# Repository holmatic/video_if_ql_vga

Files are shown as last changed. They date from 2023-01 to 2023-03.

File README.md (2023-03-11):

# **QLpicoVGA** - Video Interface QL-to-VGA with a Pi Pico 

This project creates the firmware for a DIY video interface based on the Rapsberry Pi Pico controller. It allows to connect a Sinclair QL computer to a standard VGA monitor.

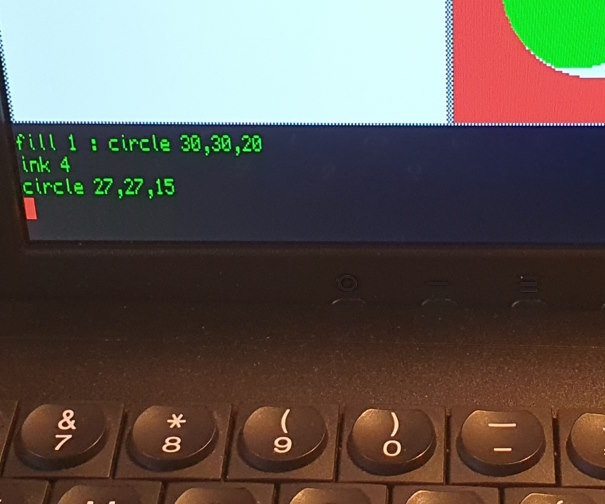
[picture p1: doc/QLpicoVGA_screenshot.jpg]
Screen VGA Monitor Connected to the QL


One difficulty when using an old Sinclair QL nowadays is finding monitor that works well. The QL video output is a bit non-standard, many displays do not show the full 512 horizontal pixel, but instead crop the screen in some way.

This small Video-to VGA converter project is specially made for the QL signal and translates the 512x256 pixel screen to a standard pseudo-XGA resolution (1024x768 with a single QL pixel translating to a block of 2x3 XGA pixels). The Gold Standard for such a translation is the "QL-VGA" FPGA-based device by MarcelK. This project is a µC based C/C++ implementation, utilizing the highly configurable I/O of the RP2040 and its DMA capabilities for signal input and output. Phase and frequency detection and adjustment is done by the CPU on the fly utilizing fixed-point arithmetics.

- The VGA signal generation uses _MoeFH_'s simple but clever DMA-driven approach for the low-level part. Kudos to _MoeFH_!
- QL video signals are sampled at 32MS/s - with the QL Pixel clock running at 10MHz
- All timing parameters are specifically preset for the QL's video output, so the software will definitely not work well with any other video source, the project is not meant as a generic RGB-to-VGA converter.
- As a small diagnostic aid, the unavoidable "No Signal" bluescreen shows a simplified logic-analyzer type of graph for the input signals

## Hardware

This project is based on a Raspberry Pi Pico board and only needs a few additional components (resistors) for voltage level translation:

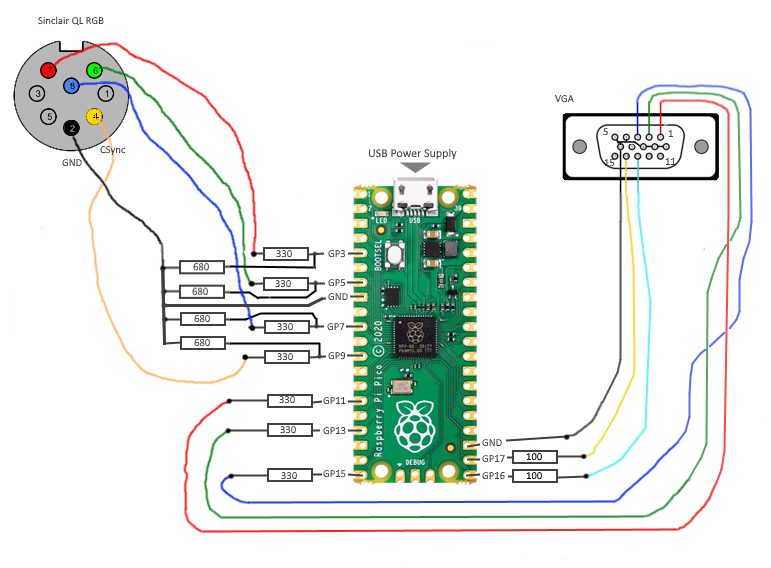
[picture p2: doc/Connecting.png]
Schematic outline How to connect QL, Pi Pico, and the VGA Monitor


```
Controller Module: Raspberry Pi Pico 
```

## QL to Pico:

```
QL RGB                            Pi Pico
Connector                          Module

7 (QLRED)   ----[R 330 Ohm]----  GP3=Pin 5 ----[R 680 Ohm]---- GND 
6 (QLGREEN) ----[R 330 Ohm]----  GP5=Pin 7 ----[R 680 Ohm]---- GND
8 (QLBLUE)  ----[R 330 Ohm]----  GP7=Pin10 ----[R 680 Ohm]---- GND

4 (QLCSYNC) ----[R 100 Ohm]----  GP9=Pin12 ----[R 680 Ohm]---- GND

2 (QLGND)   -------------------  GND=Pin8

```

## Pico to VGA:

```
Pi Pico                          VGA
Module                        Connector

GP11=Pin15 ----[R 330 Ohm]----  1 (RED)
GP13=Pin17 ----[R 330 Ohm]----  2 (GREEN)
GP15=Pin20 ----[R 330 Ohm]----  3 (BLUE)

GP16=Pin21 ----[R 100 Ohm]---- 13 (HSYNC)
GP17=Pin22 ----[R 100 Ohm]---- 14 (VSYNC)

GND=Pin23  ------------------- 6,7,8,10,5 (GND)
```

Note: Place all resistors close to the Pi Pico module (<5cm) for best signal integrity.

## Power Supply Input

Raspberry Pi Pico needs a standard USB power suppy (needs <100mA, so no special requirements for the power supply). Some VGA monitors may even provide USB voltage via an integrated USB hub. 

## 1st Prototype

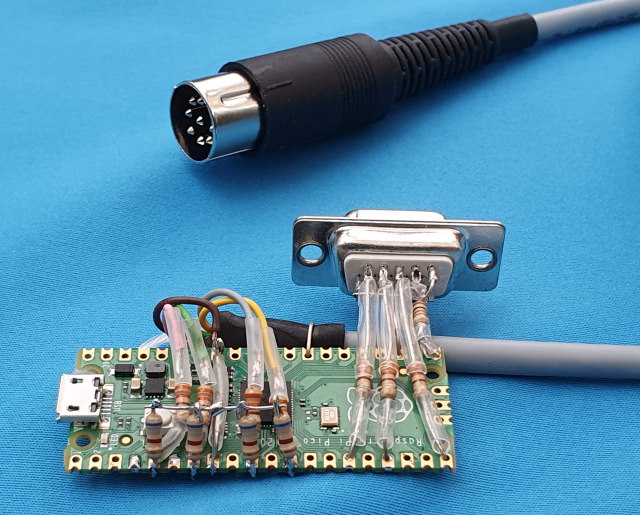
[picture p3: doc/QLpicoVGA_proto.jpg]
Prototype Quick-n-dirty prototype


(Ehem - yes I know but it works ;-)	

# Loading the Firmware into the Pi Pico

Pi Pico operates like a USB memory stick when pushing the BOOTSEL button during while plugging into the USB port of a computer. Put the firmware "video_if_ql_vga.uf2" onto the drive. LED should show short flashes with a period of about 2 seconds. Please also refer to the Pi Pico documentation regarding firmware programming.

https://github.com/holmatic/video_if_ql_vga/releases

## PCB and 3D Printable Case

So [here](doc/pcb.md) for info on creating your own PCB and case

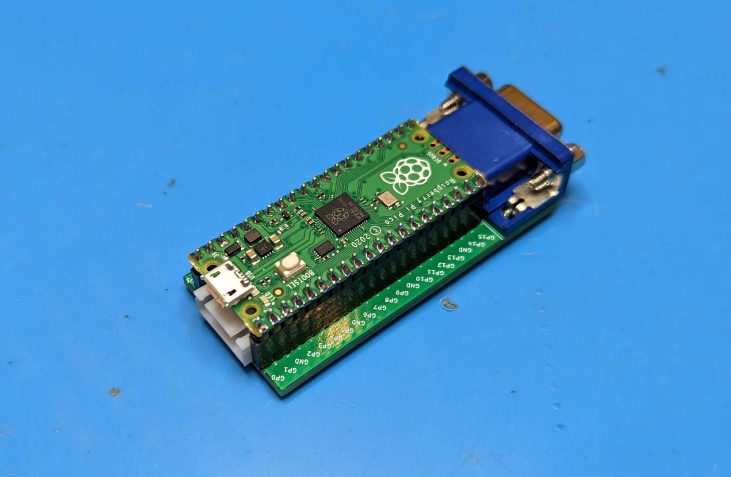
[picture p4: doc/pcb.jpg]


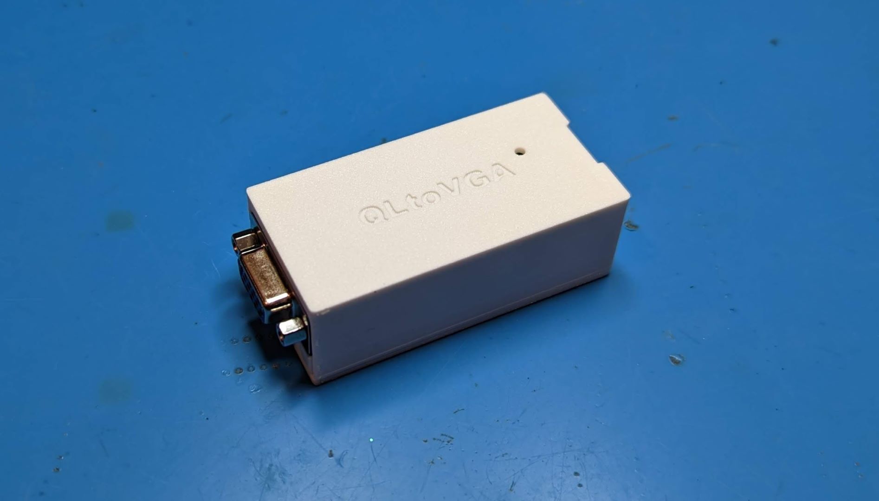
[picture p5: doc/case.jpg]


### Version Info

0.01 Initial version

0.05 Extend boot delay (startup fix for issue opbserved on some boards); minor adjustments to timing

---

Instruction v1.0

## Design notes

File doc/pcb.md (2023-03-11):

## PCB

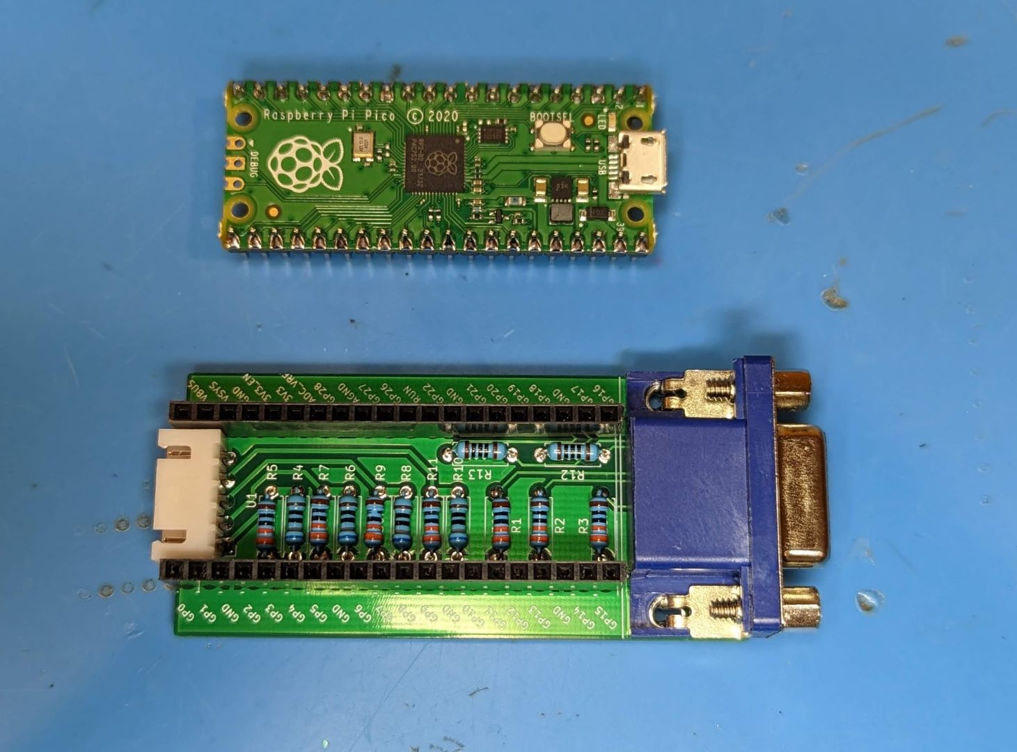
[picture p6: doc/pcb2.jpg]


To create your own PCB, send the gerber files off to your favorite PCB fab. There is an interactive BOM at [ibom.html](ibom.html), but most values are marked on the board itself.  All components can be sourced from the usual low cost Chinese vendors (AliExpress, etc.).

This is the VGA connector I used, https://www.aliexpress.us/item/2255799889288258.html

The Pico is mounted on 8.5mm tall 2.54mm female headers with 2.54mm male headers.

https://www.aliexpress.us/item/3256803886961825.html

For the video input, you can use any standard right angle 2.54mm spaced header or even solder the wires to the board. I went with an 5p XH2.54 connector which clips together a bit more securingly

https://www.aliexpress.us/item/2251832577362029.html

and then you can use the precrimped cables to make your input cable with a standard DIN 9 connector.  I sleeved the cable to make it look a little nicer, but that's optional.

https://www.aliexpress.us/item/2251832810520679.html

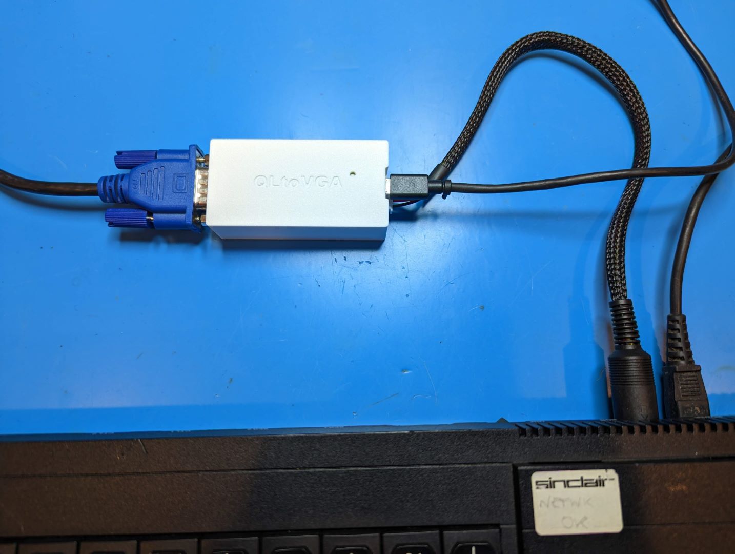
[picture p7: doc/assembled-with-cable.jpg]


## Case

The case is a simple snapfit design done in DesignSpark.  It's optimized to be printed at 0.2mm layer height with no need for supports.

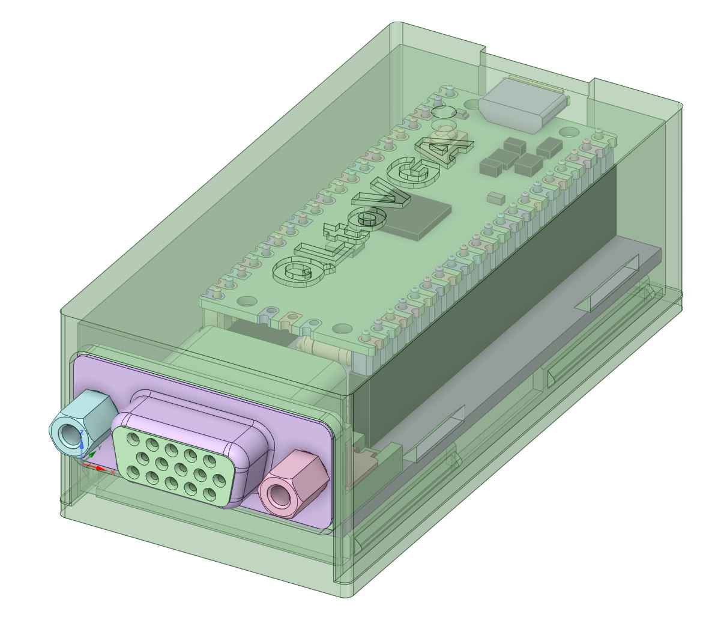
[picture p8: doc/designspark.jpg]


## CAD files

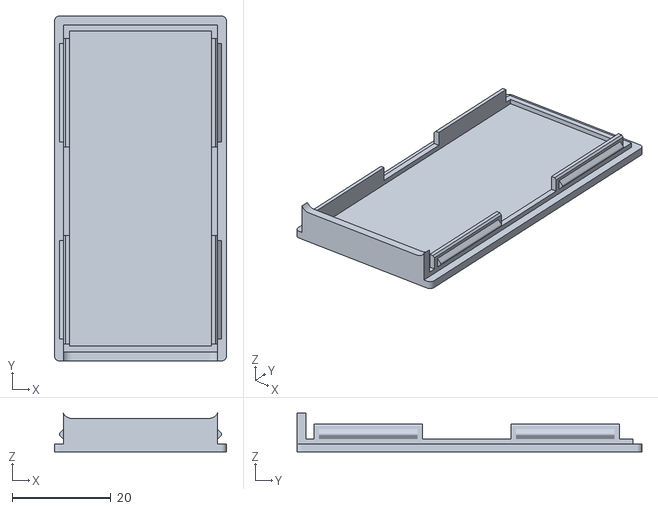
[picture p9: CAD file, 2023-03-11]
case/video_if_ql_vga-lid.stl
34.9 x 70.0 x 7.83

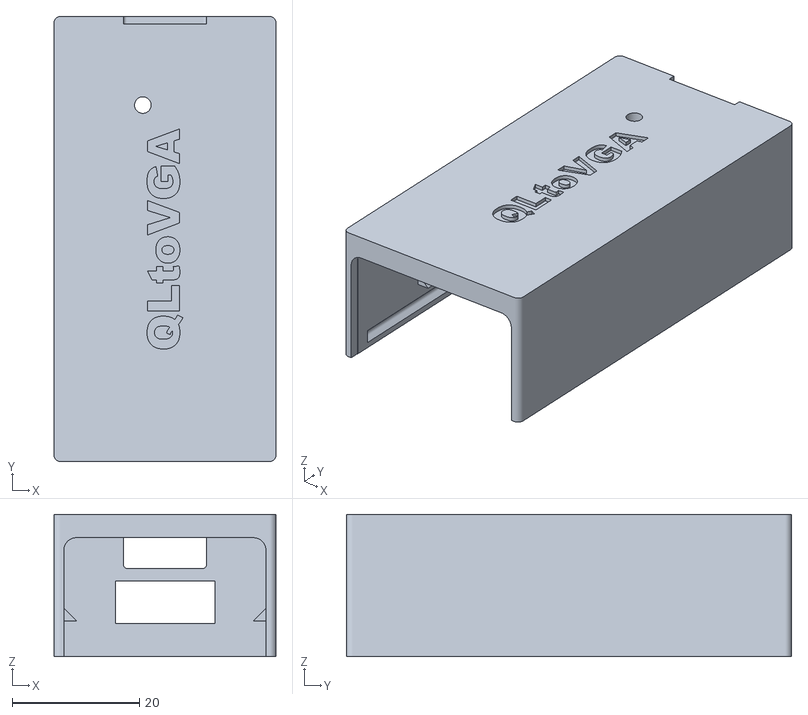
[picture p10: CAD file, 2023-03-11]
case/video_if_ql_vga-body.stl
34.9 x 70.0 x 22.4

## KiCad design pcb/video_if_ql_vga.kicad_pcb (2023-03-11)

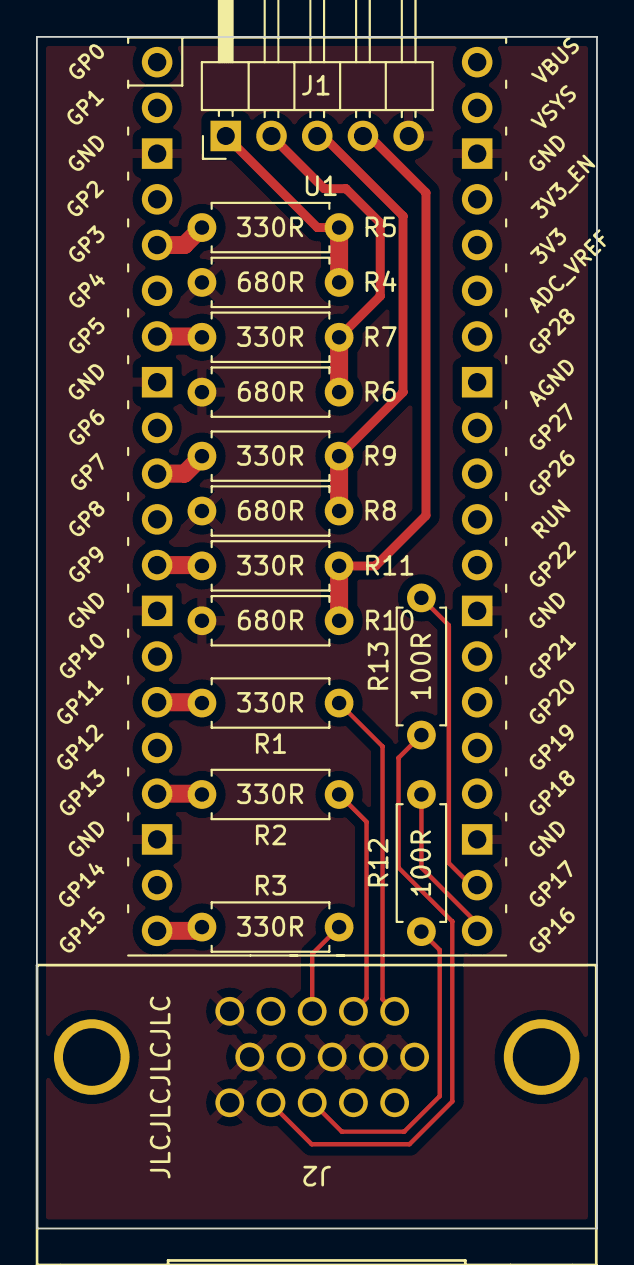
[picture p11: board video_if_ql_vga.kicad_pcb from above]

Board: 2 copper layers, 31.1 x 66.2 mm, 16 parts (0 on the bottom side), 19 nets.

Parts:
J1: Conn_01x05; PinHeader_1x05_P2.54mm_Horizontal
J2: DB15_Female_HighDensity; CONN_L77HDE15SD1CH4FVGA_AMP
R1, R2, R3, R5, R7, R9, R11: 330R; R_Axial_DIN0207_L6.3mm_D2.5mm_P7.62mm_Horizontal
R4, R6, R8, R10: 680R; R_Axial_DIN0207_L6.3mm_D2.5mm_P7.62mm_Horizontal
R12, R13: 100R; R_Axial_DIN0207_L6.3mm_D2.5mm_P7.62mm_Horizontal
U1: SC0915; RPi_Pico_SMD_TH

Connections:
/BLUE: R3.1, U1.20 (GP15)
/GREEN: R2.1, U1.17 (GP13)
/HSYNC: R12.2, U1.21 (GP16)
/QLBLUE: R9.2, U1.10 (GP7)
/QLGREEN: R7.1, U1.7 (GP5)
/QLRED: R5.2, U1.5 (GP3)
/QLSYNC: R11.1, U1.12 (GP9)
/RED: R1.1, U1.15 (GP11)
/VSYNC: R13.2, U1.22 (GP17)
GND: J1.5, J2.5, J2.6, J2.7, J2.8, J2.10, J2.15, R4.1, R6.2, R8.1, R10.2, U1.3 (GND), U1.8 (GND), U1.13 (GND), U1.18 (GND), U1.23 (GND), U1.28 (GND), U1.38 (GND)
unnamed: J1.1, R4.2, R5.1
unnamed: J1.2, R6.1, R7.2
unnamed: J1.3, R8.2, R9.1
unnamed: J1.4, R10.1, R11.2
unnamed: J2.1, R1.2
unnamed: J2.2, R2.2
unnamed: J2.3, R3.2
unnamed: J2.13, R12.1
unnamed: J2.14, R13.1

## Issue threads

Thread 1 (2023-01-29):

unable to install the provided uf2

akoutsou77, 2023-01-29:
Congratulations on this awesome project.

I have just built it and I am trying to install the uf2 you have kindly provided using the simple drag and drop approach. For some strange reason this is not working on my pico pi w. Any ideas of why is this happening would highly appreciated.

Once again congrats for this one.

holmatic, 2023-01-29:
Sorry to hear this, so far I have only tried - and heard of people using - pi picos for this, not pico W.  Not at all being a pi pico expert, I am not sure if the uf2 files are supposed to be compatible. At least the LED will not flash,  the non-W pico has the LED on GPIO25, while - from what I just read  - the pico W uses the WLAN chip for this.

akoutsou77, 2023-01-29:
Thanks for the prompt reply. I have though so too, but even the blink examples differ in size. Anyway, a friend will lent me a Pico this evening and I will move the components on that one. Once again, great project and I have noticed that you are also working on a version for the Speccy +2 timings. Great.

akoutsou77, 2023-01-31:
Nonetheless it worked fine with a plain pico pi. Congratulations

https://user-images.githubusercontent.com/105937224/215686690-ae65b1f4-48a0-4634-bfe2-45cae7829a48.mp4

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
![Uploading IMG_20230130_203148.jpg…]()

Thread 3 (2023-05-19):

Mistake in voltage divider?

pluyckx, 2023-05-19:
Hi,

My father and I are building the pcb, but we think there is a mistake in the voltage divider for connector J1. For each signal pin on J1 there is a pull down to GND and then a serie resistor to the microcontroller. We expected a serieresistor on the J1 connector and then a resistor to GND at the microcotroller pin, so the 5V signals of the J1 connector are converted to 3V3 for the microcontroller.

pluyckx, 2023-05-19:
I've made the changes on a branch I made, if you want I can create a pull request: https://github.com/pluyckx/video_if_ql_vga/tree/fix/voltage_divider.

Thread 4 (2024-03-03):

No issue, but rather a wuestion

SM7I, 2024-03-03:
What would be needed to change to make this suitable for ZX Spectrum 128k (toastrack) ?

SM7I, 2024-03-26:
Hi, do you have the time to explain how to calculate the timing parameters ? I want to try this with ZX Spectrum 128K as well....

gusmanb, 2024-03-26:
> Hi, do you have the time to explain how to calculate the timing parameters ? I want to try this with ZX Spectrum 128K as well....

I doubt to be possible to adapt this to the 128k, the QL outputs digital RGB, basically the signal is ON/OFF, that's why it has such a low color palette, but the spectrum outputs analog RGB, it has different video levels per channel and thus it can achieve the 15 color palette. Maybe using two schmitt triggers per color channel you could translate the video levels to digital signals but is not a trivial task. Also the output of the device is an on/off for each RGB channel so you will need to modify it and create some form of 2 bit DAC for each channel to reconstruct the analog output.

SimonGreenaway, 2024-04-09:
The timings are based on the FRAMES counter (50 increments per second) which the speccy has. Events (e.g. an invaders movemement) have a time in the future in which they are performed. A loop checks all the possible items and moves those with the timeout fired. It also counts how many timeouts may have been missed and uses that as a multiple for movemement. E.g. if moving the player base has missed 5 timeouts, the base is moved 5 increments. This produces a clunky movement, but at least the timing is correct compared to a faster QL.

gusmanb, 2024-04-09:
This is totally unrelated to how graphics are generated but rather to the video signals, the device samples the RGB lines based on the ql video timmings to get the pixel values, writes the sampled value to a buffer and repeats until a frame is completed and then that buffer is sent to the VGA output.

The ql generates digital video levels, very close to what cga did and so the RGB lines sampling is digital, the spectrum on the other side outputs analog rgb so it must be sampled using ADCs which are a lot slower, or doing some circuit that translates the two possible analog levels of the lines to digital.

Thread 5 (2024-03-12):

No Issue, just many thanks!

styro2000, 2024-03-12:
Many thanks for this great project!
Work great on a pico W!
My old QL (since 88 in storage..) now shows stuff on VGA!
Unfortunately, the microdrives don't read much ;-)

Silveriomrs, 2025-01-14:
Me too,
I want also to thank you for this amazing and user-friendly development!

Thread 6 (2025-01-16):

Confuse description

Silveriomrs, 2025-01-16:
Hi!

In the description of the components with the links, it seems (probably my mistake) the DIN connector to the QL as DIN-9, it seems like if the DIN male connector were 9 pins. But is not, it is 8 pins.
There is not a link to buy such connector so somebody who is not experience enough with the QL hardware could seek and buy a wrong one.

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

Thanks

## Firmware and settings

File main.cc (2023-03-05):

/*
* QLpicoVGA - Video Interface QL-to-VGA with a Pi Pico
* Copyright (C) 2023 holmatic
*
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
* You should have received a copy of the GNU General Public License
* along with this program.  If not, see <http://www.gnu.org/licenses/>.
*/






//#include <vector>
#include <cmath>
#include <cstring>
#include <stdlib.h>
#include <stdio.h>
#include <stdarg.h>

#include "pico.h"
#include "pico/stdlib.h"   // sleep_us etc
#include "pico/util/queue.h"
#include "pico/binary_info.h"
#include "hardware/clocks.h"
#include "hardware/vreg.h"
#include "hardware/gpio.h"


#include "system_defs.h"
#include "video_out/vga/vga_6bit.h"
#include "video_out/vid_render.h"
#include "sampling/sample_input.h"
#include "signalproc/video_inproc.h"




CU_REGISTER_DEBUG_PINS(generation)



// For diagnostic and error output
static queue_t dprint_queue;


void diag_printf(const char* format, ...){
    char prtbuf[32];  // on stack for reentrance
    va_list args;
    va_start (args, format);
    int num=vsnprintf(prtbuf, sizeof(prtbuf), format, args);
    va_end (args);
    for(int i=0; i<num; ++i){
        queue_try_add(&dprint_queue, &prtbuf[i]);
    }
}

size_t fw_check_diag_printf_(char* readbuf){
    size_t num = queue_get_level(&dprint_queue);
    if(num && readbuf) queue_remove_blocking(&dprint_queue, readbuf);
    return num;
}




namespace{

    void show_upper_diagnostics(VideoWindow& w1, InputSampler& ismp, bool nosignal){
        const uint32_t SAMPLESIZE=8192;
        // read some sampled data, first dummy read to recover from overrrun condition
        ismp.GetNextSampleBuffer();
        ismp.GetNextSampleBuffer();
        // collect enough buffers
        std::vector<uint8_t> smpl;
        smpl.resize(SAMPLESIZE);
        size_t wr_ix=0;
        while( wr_ix < SAMPLESIZE){
            size_t chunksize=InputSampler::BUF_SIZE;
            uint8_t* buf = ismp.GetNextSampleBuffer(true);      // blocking call
            std::memcpy(&smpl[wr_ix], buf, chunksize);
            wr_ix+=chunksize;
        }
        // plot result
        pixel_t c_hi = PixelFromRGB(0, 255, 000);
        pixel_t c_lo = PixelFromRGB(255, 255, 255);
        pixel_t c_bg = PixelFromRGB(64, 64, 128);

        w1.SetXyPos(65,25,2);
        w1.PrintF("QL pico VGA Adapter");
        w1.SetXyPos(325,33);
        w1.PrintF("by ZX TEAM 2023");

        float xscale = 460.0 / SAMPLESIZE;

        w1.SetXyPos(3, 66);
        w1.PrintF("CSync");
        w1.SetXyPos(3, 78);
        w1.PrintF(" Blue");
        w1.SetXyPos(3, 90);
        w1.PrintF("Green");
        w1.SetXyPos(3, 102);
        w1.PrintF("  Red");

        uint16_t oldxpos = 0;
        for(size_t t=0; t<SAMPLESIZE; t++){
            uint16_t xpos = 38+std::round(t*xscale);
            if(xpos!=oldxpos){
                for(uint16_t bit=0; bit<8; bit+=2){
                    // clean any previous traces
                    w1.DrawPixelRaw(xpos, 73 + bit*6, c_bg);
                    w1.DrawPixelRaw(xpos, 71 + bit*6, c_bg);
                }
                oldxpos=xpos;
            }
            for(uint16_t bit=0; bit<8; bit+=2){
                if(smpl[t] & (0x80>>bit) ){
                    // high
                    w1.DrawPixelRaw(xpos, 71 + bit*6, c_hi);
                } else {
                    // low
                    w1.DrawPixelRaw(xpos, 73 + bit*6, c_lo);
                }
            }
        }
        w1.SetXyPos(185, 145 ,2);
        w1.PrintF(nosignal ? " Signal ? ": "           " );
        w1.SetXyPos(465,205);
        w1.PrintF("v0.05");
    }



    void run_main_loop_forever(pixel_t* video_buffer)
    {
        const uint32_t diag_lines=20;
        VideoRenderer v(video_buffer);
        VideoWindow w1(&v,0, 256-diag_lines, PixelFromRGB(0, 255, 255), PixelFromRGB(64, 64, 128));
        VideoWindow w2(&v, 256-diag_lines,256, PixelFromRGB(128, 128, 128), PixelFromRGB(64, 64, 128));
        InputSampler ismp(SAMPLEIN_PIN_BASE, 32000000);
        VideoInProc vid_in(&ismp, video_buffer);


        uint32_t ok_frames=1;
        uint32_t failed_frames=0;
        uint32_t upper_diag_active=0;
        uint32_t lower_diag_active=0;

        // Draw some fancy initial pattern for the initial screen.
        auto c=PixelFromRGB(255, 0, 0);
        for(uint32_t y=0; y<256; y+=4){
            for(uint32_t x=0; x<512; x+=4){
                if(y%32==16 || x%44==36) video_buffer[y*512+x]=c;
            }
        }

        // Enter infinite loop.
        for(uint32_t cyclecount=0;;cyclecount++){

            if(gpio_get(USER_PUSHBUTTON_PIN)==0){
                ok_frames=0;
                lower_diag_active=50;
                upper_diag_active=50;
                sleep_ms(20);
            } else {
                if (vid_in.ProcessFrame(lower_diag_active ? diag_lines:0)){
                    ok_frames++;
                    failed_frames=0;
                    upper_diag_active=0;
                    w1.MarkClearPending();
                    if(!lower_diag_active) w2.MarkClearPending();
                } else {
                    failed_frames++;
                    upper_diag_active++;
                    if(failed_frames>20) ok_frames=0;
                }
            }
            if(lower_diag_active && (cyclecount%10==0) ){
                if(upper_diag_active || failed_frames)
                    w2.Clear();  // do not show the lowe part when anything is disturbing
                else{
                    w2.MarkClearPending();
                    vid_in.PrintDiagInfo();
                }
                lower_diag_active--;
            }

            gpio_put(PICO_DEFAULT_LED_PIN, (cyclecount&0x1F)<2 ? 1: 0  );

            if(upper_diag_active>=50 && (cyclecount%20==5)){
                show_upper_diagnostics(w1, ismp, failed_frames>20);
            }
            
            // collect any diagnostics
            while(fw_check_diag_printf_(NULL)){
                char c;
                fw_check_diag_printf_(&c);
                w2.PutChar(c);
            }
        }
    }


    void init_low_level_parts(pixel_t** framebuffer_pt){

        stdio_init_all();

        if(INCREASED_SYS_CLOCK){
            vreg_set_voltage(VREG_VOLTAGE_1_30);
            sleep_ms(10);
            set_sys_clock_khz(48000*5, false);  // up to 6 is used in demos, stick with 5 for now
        } else {
            set_sys_clock_khz(48000*3, false);
        }

        gpio_init(PICO_DEFAULT_LED_PIN);
        gpio_set_dir(PICO_DEFAULT_LED_PIN, GPIO_OUT);
        gpio_put(PICO_DEFAULT_LED_PIN, 1);

        // Declare the video output pins.
        bi_decl_if_func_used(bi_pin_mask_with_name(3 << (VGA_PIN_BASE + 4), "Blue 0-1"));
        bi_decl_if_func_used(bi_pin_mask_with_name(3 << (VGA_PIN_BASE + 2), "Green 0-1"));
        bi_decl_if_func_used(bi_pin_mask_with_name(3 << (VGA_PIN_BASE + 0), "Red 0-1"));
        bi_decl_if_func_used(bi_1pin_with_name(VGA_PIN_BASE + 6, "H-Sync"));   // Goes to 16
        bi_decl_if_func_used(bi_1pin_with_name(VGA_PIN_BASE + 7, "V-Sync"));      // Goes to 17

        // Declare the video input pins used for sampling
        bi_decl_if_func_used(bi_1pin_with_name( SAMPLEIN_PIN_BASE + 7, "SAMPLE C-Sync"));   // 9
        bi_decl_if_func_used(bi_1pin_with_name( SAMPLEIN_PIN_BASE + 5, "SAMPLE Blue"));     // 7
        bi_decl_if_func_used(bi_1pin_with_name( SAMPLEIN_PIN_BASE + 3, "SAMPLE Green"));    // 5  
        bi_decl_if_func_used(bi_1pin_with_name( SAMPLEIN_PIN_BASE + 1, "SAMPLE Red"));      // 3

        // Pushbutton input with pullup for diagnostcs
        gpio_init(USER_PUSHBUTTON_PIN);
        gpio_set_dir(USER_PUSHBUTTON_PIN, GPIO_IN);
        gpio_pull_up(USER_PUSHBUTTON_PIN);
        bi_decl_if_func_used(bi_1pin_with_name( USER_PUSHBUTTON_PIN, "User Pushbutton (to GND)"));      // 3

        // Some blinking.
        for(int i=0;i<3;i++){
            sleep_ms(30);
            gpio_put(PICO_DEFAULT_LED_PIN, 0);
            sleep_ms(30);
            gpio_put(PICO_DEFAULT_LED_PIN, 1);
        }

        // Init the VGA library. If for some reason this does not work (out of mem), show a blinking pattern on the LED.
        if (vga_init(&vga_mode_512x256 , VGA_PIN_BASE, reinterpret_cast<void**>(framebuffer_pt)) < 0) {
            printf("ERROR initializing VGA\n");
            fflush(stdout);
            while(1){
                gpio_put(PICO_DEFAULT_LED_PIN, 1);
                sleep_ms(1000);
                gpio_put(PICO_DEFAULT_LED_PIN, 0);
                sleep_ms(1000);
            }
        }
        vga_clear_screen(0x3F);
        queue_init(&dprint_queue, sizeof(uint8_t), 150);
        setup_default_uart();
    }
}


int main(void){
    pixel_t* framebuffer;
    init_low_level_parts(&framebuffer);
    run_main_loop_forever(framebuffer);
    return 1;
} 

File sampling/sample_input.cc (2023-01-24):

/*
* QLpicoVGA - Video Interface QL-to-VGA with a Pi Pico
* Copyright (C) 2023 holmatic
*
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
* You should have received a copy of the GNU General Public License
* along with this program.  If not, see <http://www.gnu.org/licenses/>.
*/


#include <stdio.h>
#include <stdlib.h>
#include <array>

#include "pico/stdlib.h"
#include "pico/util/queue.h"
#include "hardware/gpio.h"
#include "hardware/pio.h"
#include "hardware/dma.h"
#include "hardware/structs/bus_ctrl.h"
#include "hardware/clocks.h"
#include "../system_defs.h"
#include "sample_input.h"



static inline uint bits_packed_per_word(uint pin_count) {
    // If the number of pins to be sampled divides the shift register size, we
    // can use the full SR and FIFO width, and push when the input shift count
    // exactly reaches 32. If not, we have to push earlier, so we use the FIFO
    // a little less efficiently.
    const uint SHIFT_REG_WIDTH = 32;
    return SHIFT_REG_WIDTH - (SHIFT_REG_WIDTH % pin_count);
}

namespace SampleBuf{
    // Interrupt counter, lowest bit determines the buffer that was filled.
    uint32_t overrun_count=0;

    std::array<uint,2> dma_chan;

    // Each completion interrupt will write the number matching the filled buffer.
    // Application program can block on this waiting for next data. According to doc,
    // certain operations are interrupt save
    queue_t buf_done_queue;

    const uint32_t BUF_SZ_BITS = InputSampler::BUF_SZ_BITS;
    const uint32_t BUF_SIZE = (1<<BUF_SZ_BITS);
    const uint32_t BUF_ADDR_MASK = (1<<BUF_SZ_BITS)-1;

    // Aligned for the DMA ring address warp.
    sample_t buf[BUF_SIZE*2] __attribute__((aligned(BUF_SIZE)));


    void __isr __time_critical_func(dma_handler)() {
        static uint8_t buf_ix=0;  // last buffer index
        if(dma_channel_get_irq0_status(dma_chan[buf_ix^1])){
            buf_ix=buf_ix^1;
        } else if(dma_channel_get_irq0_status(dma_chan[buf_ix])) {
            overrun_count++; // two times the same channel, should not happen during normal operation ...
        }
        else return; // no request pending

        if(!queue_is_full(&buf_done_queue)){
            queue_try_add(&buf_done_queue,&buf_ix);
        }
        else overrun_count++;
        // Clear the interrupt request.
        dma_channel_acknowledge_irq0(dma_chan[buf_ix]);
        //dma_channel_acknowledge_irq0(dma_chan[(int_count&1)^1]);

        // TEST ONLY: buf[BUF_SIZE*((buf_ix&1)^1)+BUF_SIZE/2]=0x0f; // should be okay to override the other now
    }


};




InputSampler::InputSampler(uint32_t sample_pin_base, uint32_t clk_hz)
 : sampleclock_hz_(clk_hz), consec_reads_(0), consec_rd_overall_time_us_(0), consec_rd_wait_time_us_(0)
{
    // A queue notifies about filled buffers 
    queue_init (&SampleBuf::buf_done_queue, sizeof(uint32_t), 2); // as we only have two buffers, it does not make sense to have more than two elements in the queue
    
    // choose PIO clock divider based on the CPU clock and VGA pixel clock
    uint f_clk_sys = frequency_count_khz(CLOCKS_FC0_SRC_VALUE_CLK_SYS);
    float clock_div = ((float)f_clk_sys * 1000.f) / (float)clk_hz;
    //diag_printf("Sysclk %d kHz, factor %.2f ",f_clk_sys,(double)clock_div);

    // Grant high bus priority to the DMA, so it can shove the processors out
    // of the way. This improves sampling consistency for high data rates and smaller buffers
    // (32MHz/4KB).
    bus_ctrl_hw->priority = BUSCTRL_BUS_PRIORITY_DMA_W_BITS | BUSCTRL_BUS_PRIORITY_DMA_R_BITS;

    for(auto i=sample_pin_base; i<sample_pin_base+PIN_COUNT; i++){
        gpio_init(i);
        gpio_set_dir(i, GPIO_IN);
        gpio_pull_down(i);
    }

    // Load a program to capture n pins. This is just a single `in pins, n`
    // instruction with a wrap.
    uint16_t capture_prog_instr = pio_encode_in(pio_pins, PIN_COUNT);
    struct pio_program capture_prog = {
            .instructions = &capture_prog_instr,
            .length = 1,
            .origin = -1
    };
    PIO pio = pio1;  // pio0 for VGA
    uint sm = pio_claim_unused_sm(pio, true);  
    uint offset = pio_add_program(pio, &capture_prog);

    // Configure state machine to loop over this `in` instruction forever,
    // with autopush enabled.
    pio_sm_config c = pio_get_default_sm_config();
    sm_config_set_in_pins(&c, sample_pin_base);
    sm_config_set_wrap(&c, offset, offset);
    sm_config_set_clkdiv(&c, clock_div);
    // Note that we may push at a < 32 bit threshold if pin_count does not
    // divide 32. We are using shift-to-right, so the sample data ends up
    // left-justified in the FIFO in this case, with some zeroes at the LSBs.
    sm_config_set_in_shift(&c, true, true, bits_packed_per_word(PIN_COUNT));
    sm_config_set_fifo_join(&c, PIO_FIFO_JOIN_RX);
    pio_sm_init(pio, sm, offset, &c);

    pio_sm_set_enabled(pio, sm, false);
    pio_sm_clear_fifos(pio, sm);
    pio_sm_restart(pio, sm);

    // todo set up DMA ring buffer, interrupts, and worker callbacks
    SetupDma(pio,sm);


    //pio_sm_exec(pio, sm, pio_encode_wait_gpio(trigger_level, trigger_pin));
    pio_sm_set_enabled(pio, sm, true);

}
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

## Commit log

2023-02-12 Initial PCB and Case designs
    [video_if_ql_vga-B_Cu.gbr, video_if_ql_vga-B_Mask.gbr, video_if_ql_vga-B_Paste.gbr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]
2023-03-05 Version 1.0 PCB assembled and tested
    [video_if_ql_vga-B_Cu.gbr, video_if_ql_vga-B_Mask.gbr, video_if_ql_vga-B_Paste.gbr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]
2023-03-05 Extend start up delay to address boot issues on some boards (PR2040zero)
    [main.cc]

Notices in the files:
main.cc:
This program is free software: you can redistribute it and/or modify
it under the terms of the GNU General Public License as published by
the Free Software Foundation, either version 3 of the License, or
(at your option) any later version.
